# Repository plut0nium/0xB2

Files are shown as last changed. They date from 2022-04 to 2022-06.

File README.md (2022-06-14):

# 0xB2 - splinky
Pro-Micro/Elite-C replacement with USB-C and RP2040.

Designed for use in custom mechanical (split) keyboards, but many other uses are possible.

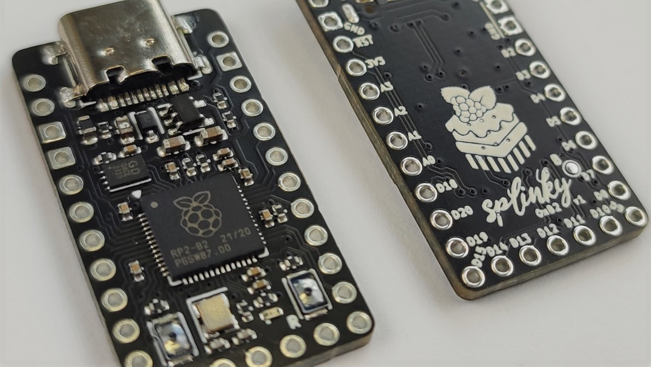
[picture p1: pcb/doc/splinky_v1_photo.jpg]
Splinky v2 Splinvy v1


## Features:

 * Pro-micro / Sparkfun RP2040 compatible footprint, with 5 extra pins at bottom (Elite-C style)
 * Raspberry Pi RP2040 MCU
 * Up to 16MB flash memory _(depending on component selection and availability)_
 * User LED & USB VBUS detect
 * Low profile USB-C mid-mount connector
 * Designed to be manufactured and assembled by all common PCBA services (including JLCPCB)

<!--![Splinky v2](pcb/doc/render_v2.png?raw=true "Splinky v2 Render")-->

## Pinout

The pinout is compatible with the widely available [SparkFun RP2040](https://www.sparkfun.com/products/18288), with extra GPIO12..16 pins broken out on the lower side.

USB VBUS detection on GPIO19.

> This pinout is a _de facto_ standard, established by actors of the MK community (see discussions in `#RP2040` on the bastardkb Discord server) 

Additionnaly, a user LED is tied to GPIO17, can be used for UF2 bootloader status indication, or any other purpose (or turned OFF, no annoying always-on power LED).

## Programming

The splinky uses a basic two-button reset circuitry.

In order to put the board in bootloader mode, press briefly the RESET button (marked **R**) while holding the BOOT button (the second one).
If the buttons are not reachable (soldered upside down), the /RST pad can be shorted to GND, while the two smaller BOOT pads (next to D8) are maintained shorted (v2 only).

## Manufacturing

Releases contain required information (gerbers, bom, pos) for assembly by JLCPCB.

## Releases

 * **v3** updated pinout - current release
 * **v2** first public release
 * **v1** first prototyping run

## Credits

 * Raspberry Pi Foundation
   * [RP2040 Datasheet](https://datasheets.raspberrypi.com/rp2040/rp2040-datasheet.pdf)
   * [Hardware design with RP2040](https://datasheets.raspberrypi.com/rp2040/hardware-design-with-rp2040.pdf)
 * [SparkFun Pro Micro - RP2040](https://www.sparkfun.com/products/18288)
 * [Adafruit kb2040](https://learn.adafruit.com/adafruit-kb2040)
 * [sea-picro](https://github.com/joshajohnson/sea-picro) - _similar project, I borrowed some cheaper component references ^^_
 * ...

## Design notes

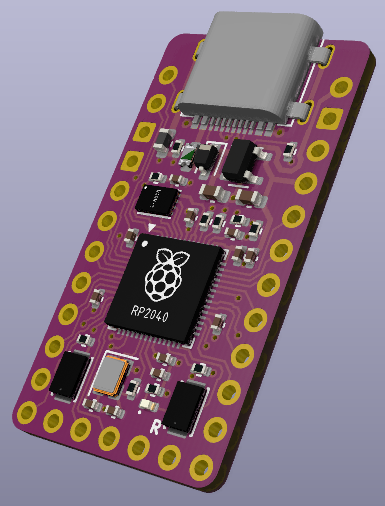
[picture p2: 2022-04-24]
pcb/doc/render_v2.png

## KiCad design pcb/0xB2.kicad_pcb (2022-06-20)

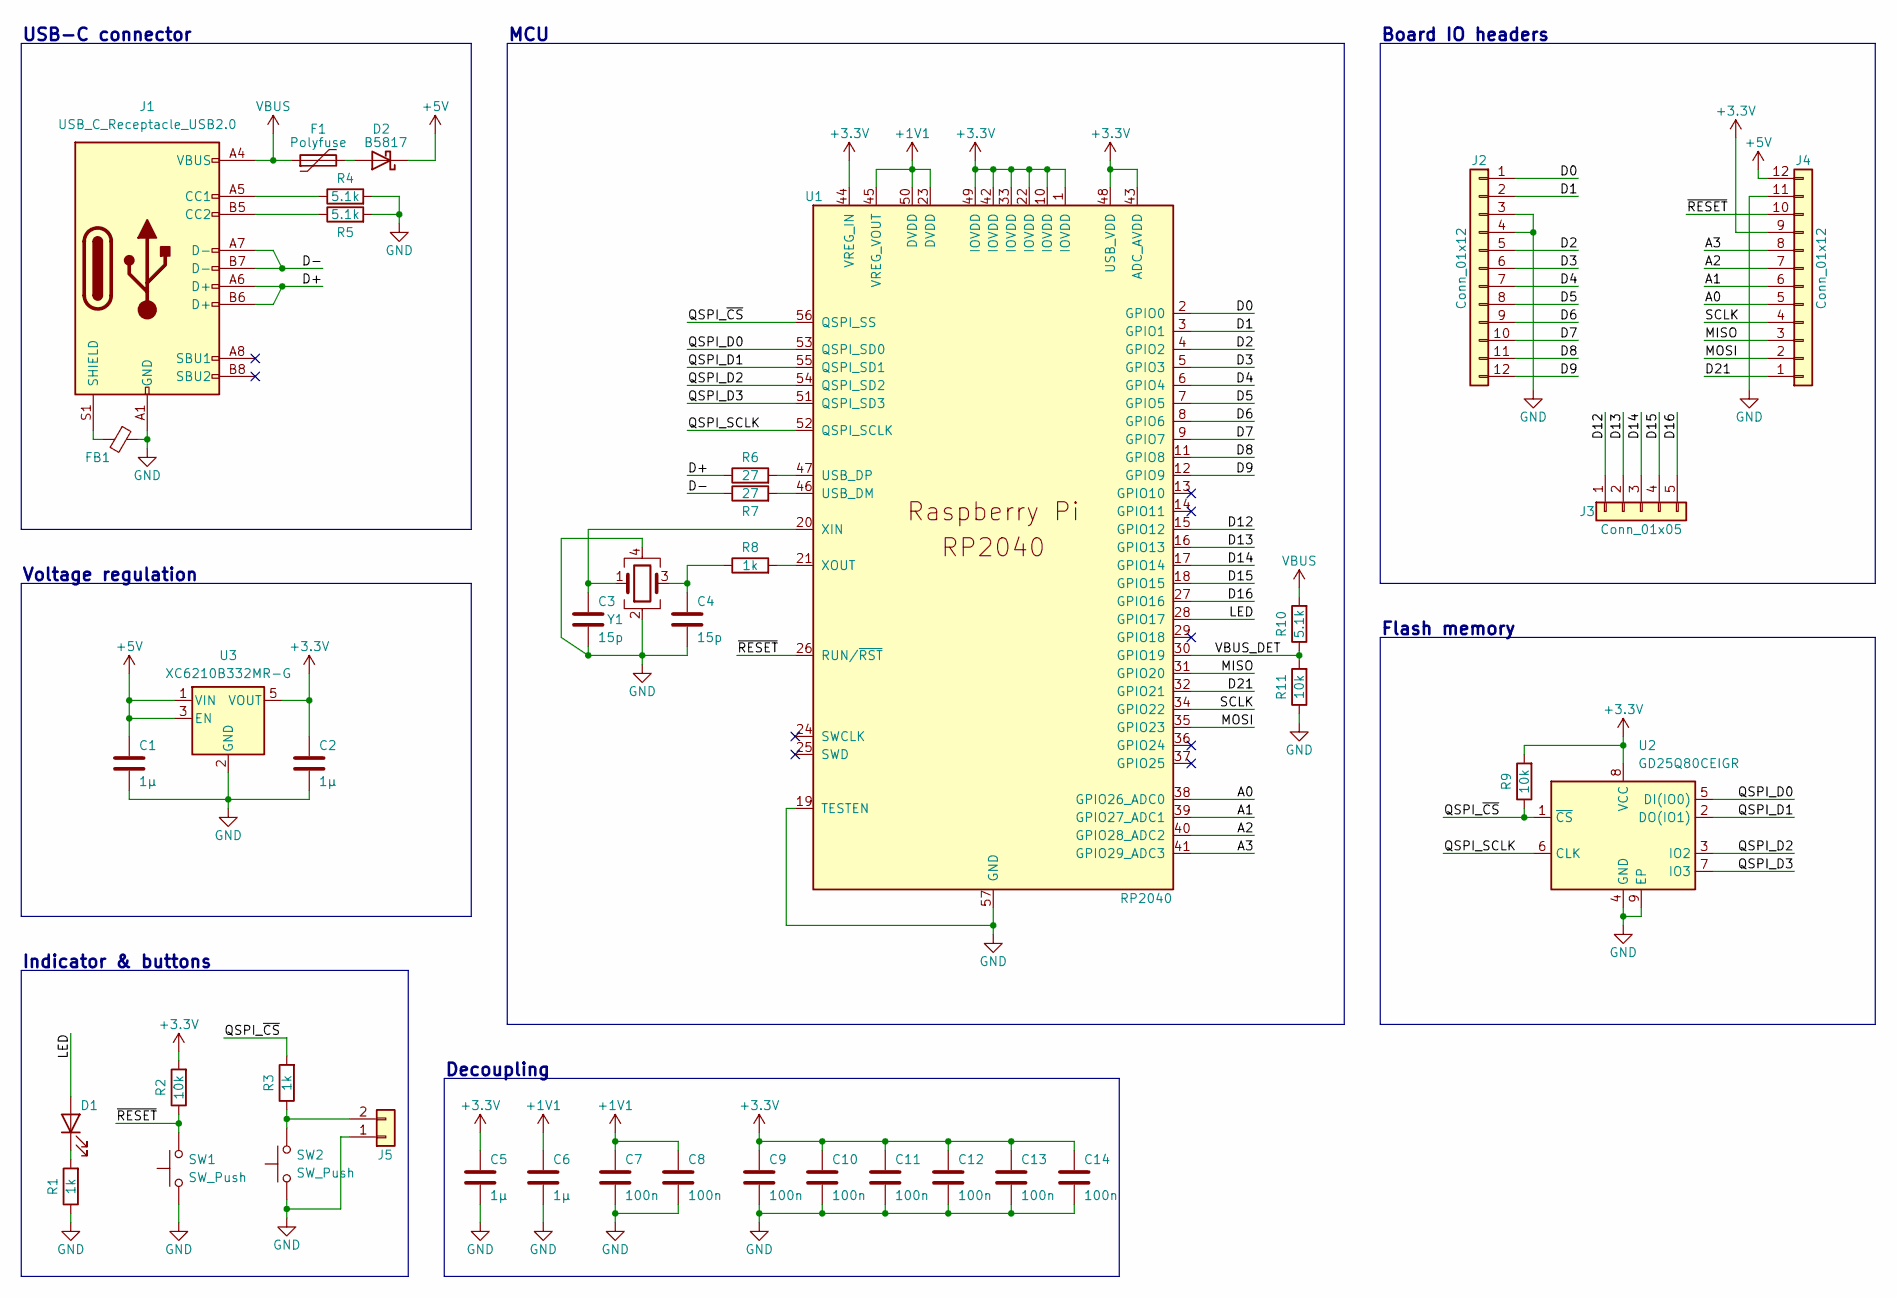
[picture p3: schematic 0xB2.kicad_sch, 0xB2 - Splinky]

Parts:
C1, C2: 1µ; C_0603_1608Metric; LCSC C19666
C3, C4: 15p; C_0402_1005Metric; LCSC C1548
C5, C6: 1µ; C_0402_1005Metric; LCSC C52923
C7, C8, C9, C10, C11, C12, C13, C14: 100n; C_0402_1005Metric; LCSC C1525
D1: LED; LED_0402_1005Metric; LCSC C130719
D2: B5817; D_SOD-323; LCSC C123899
F1: Polyfuse; Fuse_0603_1608Metric; LCSC C69679
FB1: FerriteBead_Small; L_0603_1608Metric; LCSC C98288
J1: USB_C_Receptacle_USB2.0; USB_C_Receptacle_HRO_TYPE-C-31-M-13B; LCSC C2848619
J2, J4: Conn_01x12; PinHeader_1x12_P2.54mm
J3: Conn_01x05; PinHeader_1x05_P2.54mm
J5: Conn_01x02; PinHeader_1x02_P1.27mm_Vertical
R1, R3, R8: 1k; R_0402_1005Metric; LCSC C11702
R2, R9, R11: 10k; R_0402_1005Metric; LCSC C25744
R4, R5, R10: 5.1k; R_0402_1005Metric; LCSC C25905
R6, R7: 27; R_0402_1005Metric; LCSC C25100
SW1, SW2: SW_Push; SW_SPST_CK_KXT3; LCSC C319433
U1: RP2040; QFN-56-1EP_7x7mm_P0.4mm_EP3.2x3.2mm; LCSC C2040
U2: GD25Q80CEIGR; USON-8-1EP_3x2mm_P0.5mm_EP0.25x1.65mm; LCSC C395484
U3: XC6210B332MR-G; SOT-23-5; LCSC C82942
Y1: Crystal_GND24; Crystal_SMD_2520-4Pin_2.5x2.0mm; LCSC C2149204

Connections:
+1V1: C6.1, C7.1, C8.1, U1.23 (DVDD), U1.45 (VREG_VOUT), U1.50 (DVDD)
+3V3: C2.1, C5.1, C9.1, C10.1, C11.1, C12.1, C13.1, C14.1, J4.9, R2.2, R9.2, U1.1 (IOVDD), U1.10 (IOVDD), U1.22 (IOVDD), U1.33 (IOVDD), U1.42 (IOVDD), U1.43 (ADC_AVDD), U1.44 (VREG_IN), U1.48 (USB_VDD), U1.49 (IOVDD), U2.8 (VCC), U3.5 (VOUT)
+5V: C1.1, D2.1 (K), J4.12, U3.1 (VIN), U3.3 (EN)
/A0: J4.5, U1.38 (GPIO26_ADC0)
/A1: J4.6, U1.39 (GPIO27_ADC1)
/A2: J4.7, U1.40 (GPIO28_ADC2)
/A3: J4.8, U1.41 (GPIO29_ADC3)
/D0: J2.1, U1.2 (GPIO0)
/D1: J2.2, U1.3 (GPIO1)
/D2: J2.5, U1.4 (GPIO2)
/D3: J2.6, U1.5 (GPIO3)
/D4: J2.7, U1.6 (GPIO4)
/D5: J2.8, U1.7 (GPIO5)
/D6: J2.9, U1.8 (GPIO6)
/D7: J2.10, U1.9 (GPIO7)
/D8: J2.11, U1.11 (GPIO8)
/D9: J2.12, U1.12 (GPIO9)
/D12: J3.1, U1.15 (GPIO12)
/D13: J3.2, U1.16 (GPIO13)
/D14: J3.3, U1.17 (GPIO14)
/D15: J3.4, U1.18 (GPIO15)
/D16: J3.5, U1.27 (GPIO16)
/D21: J4.1, U1.32 (GPIO21)
/D+: J1.A6 (D+), J1.B6 (D+), R6.1
/D-: J1.A7 (D-), J1.B7 (D-), R7.1
/LED: D1.2 (A), U1.28 (GPIO17)
/MISO: J4.3, U1.31 (GPIO20)
/MOSI: J4.2, U1.35 (GPIO23)
/QSPI_D0: U1.53 (QSPI_SD0), U2.5 (DI(IO0))
/QSPI_D1: U1.55 (QSPI_SD1), U2.2 (DO(IO1))
/QSPI_D2: U1.54 (QSPI_SD2), U2.3 (IO2)
/QSPI_D3: U1.51 (QSPI_SD3), U2.7 (IO3)
/QSPI_SCLK: U1.52 (QSPI_SCLK), U2.6 (CLK)
/QSPI_~CS: R3.2, R9.1, U1.56 (QSPI_SS), U2.1 (~CS)
/SCLK: J4.4, U1.34 (GPIO22)
/VBUS_DET: R10.1, R11.2, U1.30 (GPIO19)
/~RESET: J4.10, R2.1, SW1.2, U1.26 (RUN/~RST)
GND: C1.2, C2.2, C3.2, C4.2, C5.2, C6.2, C7.2, C8.2, C9.2, C10.2, C11.2, C12.2, C13.2, C14.2, FB1.1, J1.A1 (GND), J1.A12 (GND), J1.B1 (GND), J1.B12 (GND), J2.3, J2.4, J4.11, J5.1, R1.1, R4.2, R5.2, R11.1, SW1.1, SW2.1, U1.19 (TESTEN), U1.57 (GND), U2.4 (GND), U2.9 (EP), U3.2 (GND), Y1.2, Y1.4
unnamed: C3.1, U1.20 (XIN), Y1.1
unnamed: C4.1, R8.1, Y1.3
unnamed: D1.1 (K), R1.2
unnamed: D2.2 (A), F1.2
unnamed: FB1.2, J1.S1 (SHIELD)
unnamed: J1.A5 (CC1), R4.1
unnamed: J1.B5 (CC2), R5.1
unnamed: J5.2, R3.1, SW2.2
unnamed: R6.2, U1.47 (USB_DP)
unnamed: R7.2, U1.46 (USB_DM)
unnamed: R8.2, U1.21 (XOUT)
VBUS: F1.1, J1.A4 (VBUS), J1.A9 (VBUS), J1.B4 (VBUS), J1.B9 (VBUS), R10.2

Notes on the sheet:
Decoupling
Board IO headers
USB-C connector
Indicator & buttons
Voltage regulation
MCU
Flash memory

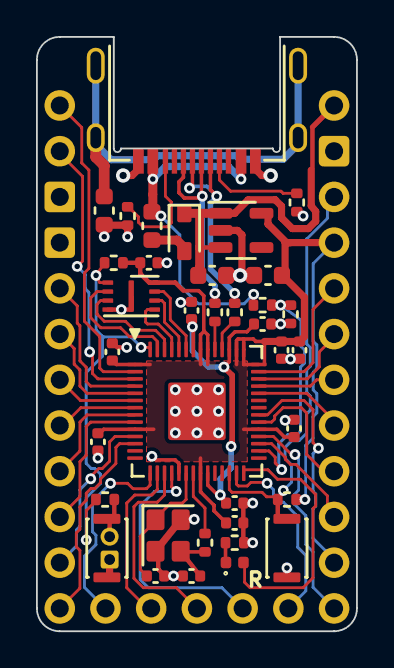
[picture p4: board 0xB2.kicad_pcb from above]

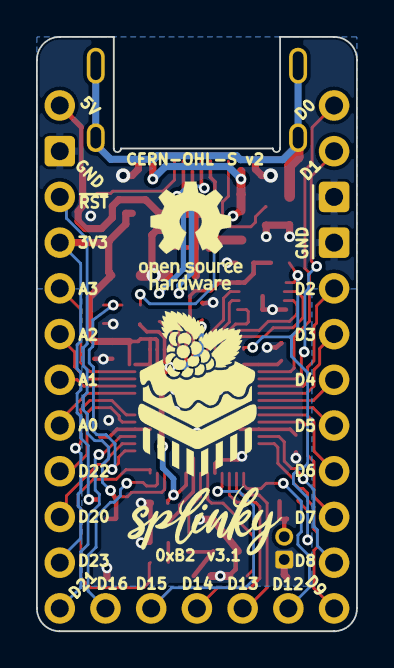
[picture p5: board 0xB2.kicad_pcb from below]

Board: 2 copper layers, 17.8 x 33.0 mm, 42 parts (2 on the bottom side), 50 nets.

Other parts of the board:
rb_cake: G*****; rb_cake
splinky: G*****; splinky

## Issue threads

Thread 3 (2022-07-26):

About Bom

F1hone, 2022-07-26:
Hello，this is a great project

I want to try to make a board myself

Could you please provide the bom sheet related to this project?

This will help me a lot, thanks

bstiq, 2022-07-27:
Hi,

The latest gerber, BOM and POS files are in the release section of this repo.
Please note, at the moment the flash chip is not available at JLC (it's possible to order it but will take some time)

F1hone, 2022-08-08:
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
Yes！
 i made it
nice design

F1hone, 2022-08-08:
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

bstiq, 2022-08-08:
Hi,

I'm glad you figured it out ! Enjoy the rp2040's power.

I'll close this issue, feel free to reopen it if there's any questions.

Here is the pinout if necessary:
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

Closed 2022-07-28.

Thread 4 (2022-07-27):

Alternative NOR flash

toniz4, 2022-07-27:
Since the main model of NOR flash seems to be unavailable, there is other models with more or less storage, that are a drop in replacement?

bstiq, 2022-07-28:
At this point we don't know of any other flash that would be a drop in replacement.
You can either wait for restock, order the parts (that is possible at JLC), or  use a different part.

Part C97521 at JLC should be a suitable replacement, but is bigger and will require modifying the PCB.

Regards,

plut0nium, 2022-07-28:
In fact, there are several other chips that could be used, but none of them seem to be stocked by JLC at the moment.

Most QSPI NOR Flash would work if they are in the same form factor (USON-8) and support 3.3V.

plut0nium, 2022-10-07:
P25Q32H-UXH-IR (JLC part# C414068) has been used by some people.
Did not test it personally, though.

Ardakilic, 2023-01-13:
Hey @plut0nium , thanks for the information! Currently, there's P25Q32H-UXH-IR available on JLCPCB, and instead of XC6210B332MR-G, I ordered some PCBs with the alternative, which is 4 MBs, and will inform about how it'll go.

I already had connectors, and I'll hand-solder them, the rest should be same.

Ardakilic, 2023-02-14:
@plut0nium Heya, I don't know if this is related, but here comes my experiment:

Out of the box, even though the module uploads the stuff, unlike the sparkfun rp2040, the keyboard could not be identified.

I was frustrated, since I produced about a dozen (I knew the risk).

As a last resort, I wanted to try KMK and CircuitPython. I uploaded [the Sparkfun Pro Micro RP2040's circuitpython uf2 file](https://circuitpython.org/board/sparkfun_pro_micro_rp2040/) to both Sparkfun pro micro rp2040, and to splinky, and it identified for both! Also the NAND size was correct! This gave me hope.

After that, I re-uploaded the qmk uf2 file, and boom! it worked nicely!

I don't know how, or why, but installing CircuitPython uf2 beforehand helped. Maybe this was needed for factory-produced modules, I don't know.

I'm currently testing the 5th module, all is same for every one of them

Ardakilic, 2023-02-15:
For the sake of the testing, I just found out this part is available on stock on JLCPCB:

MX25R8035FZUIL0 : https://jlcpcb.com/partdetail/mxic_macronix-MX25R8035FZUIL0/C152596

Which is a 8 megabyte module. I'll try it as well.

alinelena, 2023-06-14:
is this a replacement? MFR.Part # W25Q16JVUXIQ
JLCPCB Part # C2843335 to my untrained eye looks compatible... but any thoughts appreciated

original
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
vs
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

Ardakilic, 2023-06-14:
Would these ones work also, it's bigger than 16 mbits, and are in stock as well:

1. https://jlcpcb.com/partdetail/Zetta-ZD25WQ32CEIGR/C5258281
2. https://jlcpcb.com/partdetail/puya-P25Q32L_UXHIR/C559225

bstiq, 2023-06-15:
The first one you linked seems to have the same pinout, I couldn't check the nominal voltage on a quick check.
So it seems like it could work, you might need to modify the QMK code to accommodate for a different type of memory.
Same thing for the others - I haven't tested them though.

If you are buying in small quantities, I recommend also looking at off-the-shelf solutions like the liatris or even kb2040 if you don't need the bottom pins

alinelena, 2023-06-15:
C2843335, W25Q16JVUXIQ is 3V
C5258281,ZD25WQ32CEIGR, is 1.65 - 3.6V
C559225,P25Q32L-UXH-IR, is 1.65 - 2V
C414068, P25Q32H-UXH-IR is 2.3 - 3.6V this is reported as working.

Ardakilic, 2023-06-15:
Since @plut0nium mentioned if they work with 3.3v, and the pinouts match, I assume

[C5258281,ZD25WQ32CEIGR, is 1.65 - 3.6V](https://jlcpcb.com/partdetail/Zetta-ZD25WQ32CEIGR/C5258281)

Should work.

If I create a new batch for my prototype, I'll try this one.

alinelena, 2023-06-17:
> C2843335, W25Q16JVUXIQ is 3V

just to note waveshare is using this in one of theirs
https://www.waveshare.com/rp2040-tiny.htm

alinelena, 2023-06-20:
looking more into this one would expect instruction sets to match too
https://github.com/raspberrypi/pico-sdk/blob/develop/src/rp2_common/boot_stage2/boot2_w25q080.S but this is beyond me

plut0nium, 2023-09-18:
Thanks for the feedback!

I have been considering making a list of NOR chips reported working with this board... but I do not produce or sell pcbs, so have a very limited view of what's really happening right now.

wlhlm, 2023-09-30:
I had some Splinkys made with P25Q32H-UXH-IR (LCSC C414068) flash. To make QMK work I have to set
```c
#define RP2040_FLASH_GENERIC_03H
```
in `config.h`.

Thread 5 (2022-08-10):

About KMK

F1hone, 2022-08-10:

plut0nium, 2022-08-10:
Sorry, I don't know anything about CircuitPython and/or KMK...

But have you tried with the Sparkfun RP2040 version of CircuitPython: https://circuitpython.org/board/sparkfun_pro_micro_rp2040/ ?

F1hone, 2022-08-10:
It doesn't work,
I tried other rp2040 boards and none of them worked
Maybe I need to compile a uf2 file myself

plut0nium, 2022-10-07:
> I tried other rp2040 boards and none of them worked

If I understand correctly, this issue is not specific to this board.

mitswan, 2022-11-07:
Has anyone found a workaround for getting Circuitpython on this? Having the same challenge

mitswan, 2022-11-08:
For what its worth - the main difference is the flash chip GD25Q80C is not yet supported by circuitpython

bharathyes, 2024-01-26:
@mitswan where best to check / track when support for this board is added ?

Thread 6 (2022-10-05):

Flashing

sopsupreme, 2022-10-05:
hello, in order to use the splinky with QMK what should i flash the board with?
I am struggling to find firmware that works with it, so far only micropython https://micropython.org/download/rp2-pico/ , which is non-hid compliant and cannot be used with QMK toolbox. QMK is also unable to compile in UF2 files,

plut0nium, 2022-10-05:
Bastardkb has a number of example configs to use QMK on the Splinky: Scylla or Charybdis v2, Dilemma...

See here : https://github.com/qmk/qmk_firmware/tree/master/keyboards/bastardkb

sopsupreme, 2022-10-06:
i got it working! thankyou!

Closed 2022-10-06.

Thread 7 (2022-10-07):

Flash is too hard for hand solder

F1hone, 2022-10-07:
Flash packaging is a little difficult for manual welding, and lengthening the pad will be very helpful

plut0nium, 2022-10-07:
This board was not designed with manual assembly in mind.

I would recommend using a hot air station if you really want to go this way.

Closed 2022-10-07.

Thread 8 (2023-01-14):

Question about the connector

Ardakilic, 2023-01-14:
Hello,

First of all, thanks for making this project available for us all!

I'll solder the connectors myself, and ordered the rest from JLCPCB, however I have a question.

At the current state, the connectors are mid mount, so I was wondering would either of this as a connector work? Which one should I pick? The connectors I have are through hole, so I wanted to buy a batch, but wanted to ensure they fit properly (same profile as M-13B).

https://www.aliexpress.com/item/32998900371.html

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

Can you confirm please? Would this work? If so, which one?

Thanks in advance!

bstiq, 2023-01-18:
Hey,

From a quick check on the link you posted, the dimensions look close. There's a few places where they slightly differ, so you should also check both datasheets and maybe put one footprint over the other to check (in Kicad).

It looks like you might need to change the position of the pads, and the shape of the edge cut.

The datasheet on the link is too pixelated to check the pads, so you should find a pdf and check the numbering carefully (A1...A12). They have to match, so you might need to re-route some connections.

That's as far as I can see, others can feel free to chime in.

Ardakilic, 2023-01-26:
Hello @bstiq , thanks for the feedback.

Currently the PCBs are being produced, and since it's Chinese new year, it's delayed, so I cannot exactly tell how it will be. Just in case I ordered from both variants and will check the compatibility, risking sacrificing either one.

I will update here after I try it, I'd also appreciate if anyone has experience with these.

Thanks again!

Ardakilic, 2023-02-14:
Heya, I just got the boards today, I ordered without connectors to make it cost cheaper:

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

I had bought these and they were delivered already, so I just soldered them.

The 1.6 mm mid mount ones work awesome!

This is my hand soldering:

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

The other one would have also worked electronically and mechanically, but the 1.6mm was looking more proper for this.

Hand-soldering these, and using stamp holes instead of v-cuts made it cost about $20 cheaper overall (it could be assembled as cheaper level like this because of lack of a through hole component and lack of v-cut).

I hope a panel like my modified one (which JLCPCB did actually) is considered from the repo authors.

bstiq, 2023-02-15:
Hey ! Thanks for all the feedback.

Regarding the assembly costs: on my side, I use a usb-c port that requires standard assembly. I also have stocks of components and to use those I also need standard assembly. In that sense, I'm not concerned by a mousebites panel.

That's something that's also relatively easy to do in Kikit, so unless @plut0nium wants to do that specifically I think it's going to stay an option.

If you want to create a PR to add eg. the kikit options that's possible of course.

Ardakilic, 2023-02-15:
Sadly I don't know how to modify a gerber / project with KiCad and KiKit (which I believe is [this ](https://github.com/yaqwsx/KiKit) I guess) 😞

I could always upload the JLC's updated gerber to here, but I guess it will be futile since panel is generated through scripts and if you ask nicely I guess JLC could do it anyways.

I'll try to check and alter the panel if it's done through a script, I hope I can put it together with ease, but don't keep your hopes up.

Closed 2023-02-14.

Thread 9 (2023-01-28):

Suggestion: Make a stamp hole panel variant

Ardakilic, 2023-01-28:
Hello,

I'm currently producing this board, and I choose economics for parts placements, considering I will solder the connectors myself. When I do like it, the v-cut makes it 20 usd more expensive for production.

As an alternative, JLCPCB suggested using stamp holes, and updated my gerber like this:

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

So, when I decide to solder the connector myself, and use stamp holes instead of v-cut, it's almost $1 cheaper per module when you get 30 modules, just because of the selections.

I'd appreciate if this could be considered for future releases.

Thanks again for making this board available, can't wait to hold on the prototypes 😊

Ardakilic, 2023-02-14:
This all worked nicely. I got all of the assembled boards without issues, and all are running nicely. I hope this is considered for the future releases!

alinelena, 2023-06-14:
the other option is to let jlcpcb panelize them for you... bad news is you get 12 on a panel...

plut0nium, 2023-09-18:
Thanks for the feedback.

However, there are many panelizing options, some are more suited for specific uses (auto vs manual PCB assembly, cost optimization...).
The panelized version in the release is just provided for convenience, but the main deliverable remains the single-pcb cad files.

People are encouraged to panelize themselves to meet their application requirements.

Closed 2023-09-18.

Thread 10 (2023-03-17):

It doesn't work for one pin on the splinky board.

yoonsangmin, 2023-03-17:
Hello,
I flashed qmk on Splinky and it was worked fine. But suddenly the keys in the bottom row didn't work, so I checked and they were all keys connected to one pin, D9.

I connected another splinky board and my keyboard worked fine. I thought something went wrong while using the magic key code that write something on the eeprom so I reset the eeprom, but the problem doesn't go away.

How can i solve it? Is there a problem with the soldering of Arduino?

Closed 2023-03-21.

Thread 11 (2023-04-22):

While compiling for QMK, what are the AVR pin definitions for bottom rows?

Ardakilic, 2023-04-22:
Hello,

While we compile a QMK (and ZMK) Firmware for the splinky boards, we tried GPIO values for bottom row pins.

If we use GP12...GP16 and use `-e CONVERT_TO=promicro_rp2040` it gives undefined error for GP12...GP16 pin definitions.

What are the values for bottom row pins for AVR ? Is it pin-compatible with Elite-C?

Elite-C for reference:

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

Thanks in advance!

Ardakilic, 2023-04-22:
I don't have a means to try, but while checking the compilers on the qmk repository, found this:

```c
// Bottom row
#define B7 12U
#define D5 13U
#define C7 14U
#define F1 15U
#define F0 16U
```

Since b0 and d5 are LED pins on classic blue pro micros, then adding this anywhere in keymap and adding `-e CONVERT_TO=elite_pi` should suffice, right?

```c
// Bottom row
#define B7 12U
// #define D5 13U // prevent re-defining error
#define C7 14U
#define F1 15U
#define F0 16U
```

Ardakilic, 2023-04-26:
Update: Can confirm, definitions of these do work. Thanks!

Closed 2023-04-26.

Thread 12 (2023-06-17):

are gerbers ok (v3.2)

alinelena, 2023-06-17:
I am looking into printing few of these i upload the single board and choose panelise by pcb 4x2 but then when they show me the parts placements looks like this, notice usb type c not in place... similar if I choose the panelized version from the repo.

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

also i notice my replacement nor does not show.. i went with this, C5258281, this check with them

plut0nium, 2023-06-19:
The bad placement of the USB-C is a common issue, and is usually solved by JLCPCB operators during the final review.

Many people have used the gerbers without reported issue.

alinelena, 2023-06-19:
thank you! I assumed show but I wanted to have it triple checked.

Closed 2023-07-12.

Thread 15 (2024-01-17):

Which version of CircuitPython to be flashed ?

bharathyes, 2024-01-17:
Currently building a Lily58 PRO with Splinky as the controller.

Stuck at writing the firmware to the board.

Which version of CircuitPython needs to be flashed for setting up KMK ?

From the [firmware downloads page](https://circuitpython.org/downloads?q=2040) I have tried the following : Adafruit KB2040, Sparkfun Pro Micro RP2040 and even the Raspberry Pi Pico.

None of the seem to work and the device boots back named just RPI-RP2 rather than CIRCUIT-PY or similar as it does in the RPI Pico board.

Any help on setting up the Lily58 keyboard would be appreciated.

plut0nium, 2024-01-18:
According to issue #5 this depends on the model and characteristics of the NOR flash chip that was used.

I do not have any experience with CircuitPython and/or KMK, so I'm afraid I can't provide any support on this matter.
This repository is dedicated on the hardware design of the controller board.

bharathyes, 2024-01-26:
Okay thanks. Will follow that issue to keep track of when support is added.

Closed 2024-01-26.

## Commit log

2022-03-13 PCB data
    [0xB2.kicad_pcb, 0xB2.kicad_sch]
2022-03-13 Minor routing corrections
    [0xB2.kicad_pcb]
2022-03-13 Add silkscreen drawing
    [0xB2.kicad_pcb]
2022-03-14 Smaller crystal footprint > 2520
    [0xB2.kicad_pcb, 0xB2.kicad_sch]
2022-03-14 Add BOOT pad on bottom layer
    [0xB2.kicad_pcb, 0xB2.kicad_sch]
2022-03-14 New ref for D2
    [0xB2.kicad_sch]
2022-03-14 Silkscreen update
    [0xB2.kicad_pcb]
2022-03-17 Add USB VBUS detect on GPIO 25
    [0xB2.kicad_pcb, 0xB2.kicad_sch]
2022-03-17 Prepare BOM & POS for pre-release
    [0xB2.kicad_pcb]
2022-04-20 Break out 5V instead of VBUS + routing update
    [0xB2.kicad_pcb, 0xB2.kicad_sch]
2022-04-20 Make the pinout compatible with KB2040
    WARNING !!! Breaks the compatibility with v1
    [0xB2.kicad_pcb, 0xB2.kicad_sch]
2022-04-21 Minor routing changes
    [0xB2.kicad_pcb, 0xB2.kicad_sch]
2022-04-21 Change to Sparkfun RP2040 pinout
    [0xB2.kicad_pcb, 0xB2.kicad_sch]
2022-04-22 Add pins for BOOT from the back
    [0xB2.kicad_pcb, 0xB2.kicad_sch]
2022-04-22 README and doc update
    [0xB2.kicad_pcb, 0xB2.kicad_sch]
2022-04-24 silkscreen correction
    [0xB2.kicad_pcb]
2022-04-27 Get v2 ready for manufacturing
    [0xB2.kicad_pcb, 0xB2.kicad_sch]
2022-06-14 Update pinout
    Use of the agreed pinout (see discussions on bkb discord)
    for bottom row and VBUS detect.
    Maintain compatibility with Sparkfun RP2040.
    [0xB2.kicad_pcb, 0xB2.kicad_sch]
2022-06-15 Switch USB-C connector
    [0xB2.kicad_pcb, 0xB2.kicad_sch]

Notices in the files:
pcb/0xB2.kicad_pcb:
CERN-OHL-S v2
